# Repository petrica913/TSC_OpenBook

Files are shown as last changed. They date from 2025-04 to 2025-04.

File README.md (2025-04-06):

# 📘 OpenBook - EBook Reader with ESP32-C6

## 📊 Block diagram
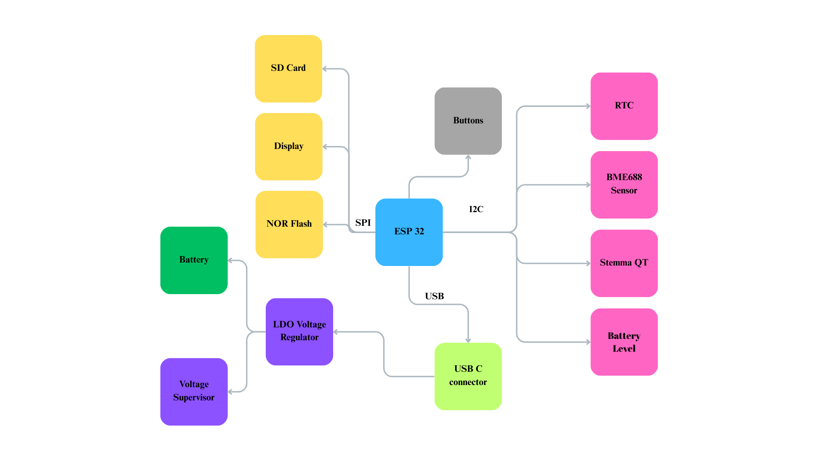
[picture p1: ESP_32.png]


## 🧠 Detailed Hardware Description

### Microcontroller
- **ESP32-C6-WROOM-1-N8** – Main MCU with WiFi 6 and BLE 5.0 support.
- Manages all components and communication interfaces.

### Power Supply
- **USB-C Connector (J2)** – for powering and charging the device.
- **MCP73831** – LiPo battery charging IC.
- **P-Channel MOSFETs (Q1, Q2)** – for automatic switching between USB and battery power.
- **Varistor and 5.1kΩ resistors** – for overvoltage protection and USB-C detection.

### Display
- **eInk display** controlled via **SPI** interface:
  - Lines: CLK, MOSI, CS, DC (Data/Command), RST (Reset), BUSY (status).
  - Extremely power-efficient – consumes power only during screen refresh.

### User Interface
- Physical buttons for menu control:
  - Left/Right navigation and Select.
  - Connected to GPIOs configured as input, some with pull-up/down resistors.

### Sensors (optional)
- **BME680** – temperature, humidity, pressure, and VOC sensor.
  - Communicates via I2C.
  - Connected to GPIOs with 10kΩ pull-up resistors.

### Other Components
- Resistors, filtering and decoupling capacitors.
- Status LEDs (optional).

## 🔋 Estimated Power Consumption

| Component | Estimated Current |
|---|---|
| ESP32-C6 (CPU active, without Wi-Fi) | ~80–120 mA |
| E-Paper (page refresh) | ~10–15 mA *(only during refresh)* |
| MicroSD (active access) | ~30–60 mA |
| RTC DS3231 | ~0.2 mA |
| BME688 Sensor (1Hz) | ~3.7 µA |
| Fuel Gauge MAX17048 (active) | ~23 µA |
| LDO Regulator (quiescent current) | ~1 µA |
| **Total estimated (without refresh)** | **~110–130 mA** |
| **Total during EPD refresh** | **~140–170 mA** |

## 🔌 Pin Allocation of ESP32-C6

| Pin Number | GPIO | Function | Componenta | Reason for Use |
|---|---|---|---|---|
| 3 | EN | Reset | Reset Button | Hardware-defined enable pin |
| 8 | GPIO0 | SQW/INT | RTC DS3231SN Interrupt | Used to wakeup from sleep using an interrupt from RTC  |
| 9 | GPIO1 | 32KHz input | RTC DS3231SN 32KHz output | Low power timing source for RTC operations |
| 27 | GPIO2 | MISO | SD Card, E-Paper, NOR Flash | SPI MISO - receives data from connected peripherals |
| 28 | GPIO3 | EPD_BUSY | E-Paper Display busy signal | Indicates the status of the E-Paper display |
| 30 | GPIO4 | SD_CS | SD Card chip select | Selects the SD card on the SPI bus |
| 31 | GPIO5 | EPD_DC | E-Paper Display data/command | Distinguishes data/command |
| 32 | GPIO6 | SCK | SD Card, E-Paper, NOR Flash | SPI clock line |
| 33 | GPIO7 | MOSI | SD Card, E-Paper, NOR Flash | SPI data line |
| 10 | GPIO8 | Pull-up | Reserved - Unused | Left free |
| 13 | GPIO9 | Boot | Boot Button | Enter flashing mode |
| 14 | GPIO10 | EPD_CS | E-Paper Display chip select | Selects E-Paper |
| 15 | GPIO11 | FLASH_CS | NOR Flash chip select | Selects external flash |
| 16 | GPIO12 | USB_D- | USB Data negative | USB data line |
| 17 | GPIO13 | USB_D+ | USB Data positive | USB data line |
| 23 | GPIO15 | Navigation | Change Button | Input detection |
| 25 | GPIO16 | TX | Test Pad | TX |
| 24 | GPIO17 | RX | Test Pad | RX |
| 16 | GPIO18 | RTC_RST | RTC reset | Resets RTC module |
| 17 | GPIO19 | I2C_PW | BME688 power control | Powers I2C modules |
| 18 | GPIO20 | EPD_3V3 | DMG2305UX-7 | Controls power supply to E-Paper display |
| 19 | GPIO21 | SDA | I2C data (RTC, BME688, Battery Gauge) | I2C data line |
| 20 | GPIO22 | SCL | I2C clock (RTC, BME688, Battery Gauge)| I2C clock line |
| 21 | GPIO23 | EPD_RST | E-Paper Display reset | Resets the display |

## 📋 Bill of Materials (BOM)
[The bill of materials can be found here](Manufacturing/BOM_OpenBook.csv)

## 🎬 Video of the OpenBook
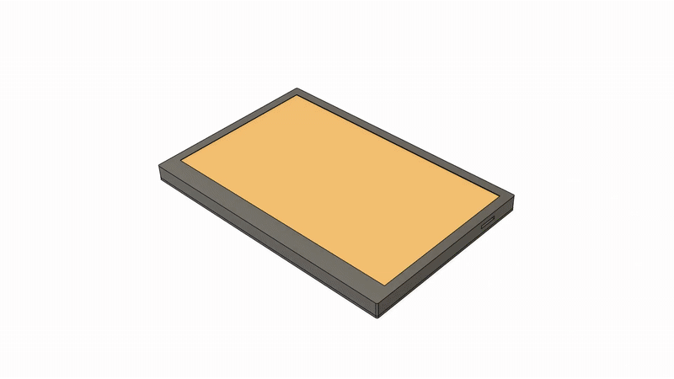
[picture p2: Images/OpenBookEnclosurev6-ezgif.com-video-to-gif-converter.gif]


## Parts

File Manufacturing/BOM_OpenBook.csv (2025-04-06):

Qty | Value | Device | Package | Parts | Description | ARROW_PART_NUMBER | ARROW_PRICE-STOCK | AVAILABILITY | CENTROID_NOT_SPECIFIED | CHECK_PRICES | COPYRIGHT | DATASHEET | DESCRIPTION | DIGIKEY_DESCRIPTION | DIGIKEY_PART_NUMBER | HEIGHT | LEAD_FREE | MANUFACTURER_NAME | MANUFACTURER_PART_NUMBER | MF | MFR_NAME | MOUSER_PART_NUMBER | MOUSER_PRICE-STOCK | MOUSER_TESTING_PART_NUMBER | MOUSER_TESTING_PRICE-STOCK | MP | MPN | PACKAGE | POPULARITY | PREFIX | PRICE | PRODUCT | PROD_ID | PURCHASE-URL | ROHS | SNAPEDA_LINK | SPICEMODEL | SPICEPREFIX | TANT | TEMPERATURE_RANGE_HIGH | TEMPERATURE_RANGE_LOW | TP_SIGNAL_NAME | VALUE
1 |  | ADAFRUIT_LEDCHIP-LED0603 | ADAFRUIT_CHIP-LED0603 | CHG_LED | LED |  |  |  |  | https://www.snapeda.com/parts/KP-1608SURCK/Kingbright/view-part/?ref=search&t=LED%200603
1 |  | SJ | SJ | SJ1 | SMD solder JUMPER |  |  |  |  | https://grabcad.com/library/solder-jumpers-1 |  |  |  |  |  |  |  |  |  |  |  |  |  |  |  |  |  |  | 3
1 | 0.1uF/50V | EAGLE-LTSPICE_CC0402 | EAGLE-LTSPICE_C0402 | EPD_C5 | CAPACITOR, European symbol |  |  |  |  | https://eu.mouser.com/ProductDetail/KEMET/C0805C104K8RACAUTO?qs=ds50AKTGxA8vmn6TMGYnqg%3D%3D |  |  |  |  |  |  |  |  |  |  |  |  |  |  |  |  |  |  |  |  |  |  |  |  |  |  | NONE | C
1 | 0.47 | ESP32_WROVER_EAGLE-LTSPICE_RR0402 | ESP32_WROVER_EAGLE-LTSPICE_R0402 | R3 | RESISTOR, European symbol |  |  |  |  | https://componentsearchengine.com/part-view/R0402%201%25%20100%20K%20(RC0402FR-07100KL)/YAGEO |  |  |  |  |  |  |  |  |  |  |  |  |  |  |  |  |  |  |  |  |  |  |  |  |  |  | NONE | R
1 | 100k | ESP32_WROVER_EAGLE-LTSPICE_RR0402 | ESP32_WROVER_EAGLE-LTSPICE_R0402 | R1_PWRUSB | RESISTOR, European symbol |  |  |  |  | https://componentsearchengine.com/part-view/R0402%201%25%20100%20K%20(RC0402FR-07100KL)/YAGEO |  |  |  |  |  |  |  |  |  |  |  |  |  |  |  |  |  |  |  |  |  |  |  |  |  |  | NONE | R
8 | 100nF | EAGLE-LTSPICE_CC0402 | EAGLE-LTSPICE_C0402 | C1, C2, C4_USB, C6, C8, C9, C10, C_DELAY | CAPACITOR, European symbol |  |  |  |  | https://eu.mouser.com/ProductDetail/KEMET/C0805C104K8RACAUTO?qs=ds50AKTGxA8vmn6TMGYnqg%3D%3D |  |  |  |  |  |  |  |  |  |  |  |  |  |  |  |  |  |  |  |  |  |  |  |  |  |  | NONE | C
1 | 100uF | RCL_CPOL-EUCT3528 | RCL_CT3528 | C3 | POLARIZED CAPACITOR, European symbol |  |  |  |  | https://www.snapeda.com/parts/20TDC100MYF/Panasonic/view-part/ |  |  |  |  |  |  |  |  |  |  |  |  |  |  |  |  |  |  | 0 |  |  |  |  |  |  |  |  | C
16 | 10K | ESP32_WROVER_EAGLE-LTSPICE_RR0402 | ESP32_WROVER_EAGLE-LTSPICE_R0402 | R1, R1_PINH, R1_PINH1, R2_PINH, R2_PINH1, R4, R5, R6, R7, R8, R9, R10, R_BOOT, R_CHANGE, R_CL1, R_RESET | RESISTOR, European symbol |  |  |  |  | https://componentsearchengine.com/part-view/R0402%201%25%20100%20K%20(RC0402FR-07100KL)/YAGEO |  |  |  |  |  |  |  |  |  |  |  |  |  |  |  |  |  |  |  |  |  |  |  |  |  |  | NONE | R
1 | 10uF | EAGLE-LTSPICE_CC0402 | EAGLE-LTSPICE_C0402 | C7 | CAPACITOR, European symbol |  |  |  |  | https://eu.mouser.com/ProductDetail/KEMET/C0805C104K8RACAUTO?qs=ds50AKTGxA8vmn6TMGYnqg%3D%3D |  |  |  |  |  |  |  |  |  |  |  |  |  |  |  |  |  |  |  |  |  |  |  |  |  |  | NONE | C
1 | 112A-TAAR-R03_ATTEND | 112A-TAAR-R03_ATTEND | 112ATAARR03ATTEND | J4 | Micro SD Card Socket, Push-Push Type, Top Mount, SMT, H=1.83mm, 10u |  |  |  |  | https://store.comet.srl.ro/Catalogue/Product/43497/ |  |  | Micro SD Card Socket | Push-Push Type | Top Mount | SMT | H=1.83mm | 10u |  |  | 1.9mm |  | ATTEND | 112A-TAAR-R03 ATTEND
1 | 15 | ESP32_WROVER_EAGLE-LTSPICE_RR0402 | ESP32_WROVER_EAGLE-LTSPICE_R0402 | R_CAPACITOR | RESISTOR, European symbol |  |  |  |  | https://componentsearchengine.com/part-view/R0402%201%25%20100%20K%20(RC0402FR-07100KL)/YAGEO |  |  |  |  |  |  |  |  |  |  |  |  |  |  |  |  |  |  |  |  |  |  |  |  |  |  | NONE | R
1 | 1uF | EAGLE-LTSPICE_CC0402 | EAGLE-LTSPICE_C0402 | C5 | CAPACITOR, European symbol |  |  |  |  | https://eu.mouser.com/ProductDetail/KEMET/C0805C104K8RACAUTO?qs=ds50AKTGxA8vmn6TMGYnqg%3D%3D |  |  |  |  |  |  |  |  |  |  |  |  |  |  |  |  |  |  |  |  |  |  |  |  |  |  | NONE | C
9 | 1uF/50V | EAGLE-LTSPICE_CC0402 | EAGLE-LTSPICE_C0402 | EPD_C1, EPD_C2, EPD_C6, EPD_C7, EPD_C8, EPD_C9, EPD_C10, EPD_C11, EPD_C12 | CAPACITOR, European symbol |  |  |  |  | https://eu.mouser.com/ProductDetail/KEMET/C0805C104K8RACAUTO?qs=ds50AKTGxA8vmn6TMGYnqg%3D%3D |  |  |  |  |  |  |  |  |  |  |  |  |  |  |  |  |  |  |  |  |  |  |  |  |  |  | NONE | C
1 | 2.2 | ESP32_WROVER_EAGLE-LTSPICE_RR0402 | ESP32_WROVER_EAGLE-LTSPICE_R0402 | R2 | RESISTOR, European symbol |  |  |  |  | https://componentsearchengine.com/part-view/R0402%201%25%20100%20K%20(RC0402FR-07100KL)/YAGEO |  |  |  |  |  |  |  |  |  |  |  |  |  |  |  |  |  |  |  |  |  |  |  |  |  |  | NONE | R
1 | 200 | ESP32_WROVER_EAGLE-LTSPICE_RR0402 | ESP32_WROVER_EAGLE-LTSPICE_R0402 | R1_BAT | RESISTOR, European symbol |  |  |  |  | https://componentsearchengine.com/part-view/R0402%201%25%20100%20K%20(RC0402FR-07100KL)/YAGEO |  |  |  |  |  |  |  |  |  |  |  |  |  |  |  |  |  |  |  |  |  |  |  |  |  |  | NONE | R
1 | 20V/4.2A/52mO/1.4W | ESP32_WROVER_SPARKFUN-DISCRETESEMI_MOSFET_PCH-DMG2305UX-7 | ESP32_WROVER_SPARKFUN-DISCRETESEMI_SOT23-3 | Q1 | P-channel MOSFETs |  |  |  |  | https://componentsearchengine.com/part-view/DMG2305UX-7/Diodes%20Incorporated |  |  |  |  |  |  |  |  |  |  |  |  |  |  |  |  |  |  |  |  |  |  | TRAN-14388 |  |  |  |  |  |  |  |  |  | 20V/4.2A/52mO/1.4W
1 | 20V/4.2A/52mO/1.4W | ESP32_WROVER_SPARKFUN-DISCRETESEMI_MOSFET_PCH-DMG2305UX-7 | ESP32_WROVER_SPARKFUN-DISCRETESEMI_SOT23-3 | Q2 | P-channel MOSFETs |  |  |  |  | https://componentsearchengine.com/part-view/DMG2305UX-7/Diodes%20Incorporated |  |  |  |  |  |  |  |  |  |  |  |  |  |  |  |  |  |  |  |  |  | DMG2305UX-7 | TRAN-14388 |  |  |  |  |  |  |  |  |  | 20V/4.2A/52mO/1.4W
1 | 2K | ESP32_WROVER_EAGLE-LTSPICE_RR0402 | ESP32_WROVER_EAGLE-LTSPICE_R0402 | R2_BAT | RESISTOR, European symbol |  |  |  |  | https://componentsearchengine.com/part-view/R0402%201%25%20100%20K%20(RC0402FR-07100KL)/YAGEO |  |  |  |  |  |  |  |  |  |  |  |  |  |  |  |  |  |  |  |  |  |  |  |  |  |  | NONE | R
5 | 4.7uF | EAGLE-LTSPICE_CC0402 | EAGLE-LTSPICE_C0402 | C1_BAT, C1_BAT1, C1_BAT2, C2_BAT, C5_USB | CAPACITOR, European symbol |  |  |  |  | https://eu.mouser.com/ProductDetail/KEMET/C0805C104K8RACAUTO?qs=ds50AKTGxA8vmn6TMGYnqg%3D%3D |  |  |  |  |  |  |  |  |  |  |  |  |  |  |  |  |  |  |  |  |  |  |  |  |  |  | NONE | C
1 | 4.7uF/25V | EAGLE-LTSPICE_CC0402 | EAGLE-LTSPICE_C0402 | C4 | CAPACITOR, European symbol |  |  |  |  | https://eu.mouser.com/ProductDetail/KEMET/C0805C104K8RACAUTO?qs=ds50AKTGxA8vmn6TMGYnqg%3D%3D |  |  |  |  |  |  |  |  |  |  |  |  |  |  |  |  |  |  |  |  |  |  |  |  |  |  | NONE | C
2 | 5k1 | ESP32_WROVER_EAGLE-LTSPICE_RR0402 | ESP32_WROVER_EAGLE-LTSPICE_R0402 | R1-USB, R2-USB1 | RESISTOR, European symbol |  |  |  |  | https://componentsearchengine.com/part-view/R0402%201%25%20100%20K%20(RC0402FR-07100KL)/YAGEO |  |  |  |  |  |  |  |  |  |  |  |  |  |  |  |  |  |  |  |  |  |  |  |  |  |  | NONE | R
1 | 744043680IND_4828-WE-TPC_WRE | 744043680IND_4828-WE-TPC_WRE | IND_4828-WE-TPC_WRE | L1 |  |  |  |  |  | https://eu.mouser.com/ProductDetail/Wurth-Elektronik/744043680?qs=PGXP4M47uW6VkZq%252BkzjrHA%3D%3D | Copyright (C) 2024 Ultra Librarian. All rights reserved. |  |  |  |  |  |  |  | 68uH |  | Wurth Electronics
1 | BD5229G-TR | BD5229G-TR | SOT95P280X125-5N | IC1 | Voltage Detector with Adjustable Delay Time: CMOS processes are utilized to develop high precision, low current consumption CMOS reset ICs that allow arbitrary setting of the delay time. The extensive lineup includes both Nch Open Drain and CMOS output types in a wide range of detection voltages (from 2.3V to 6.0V, in 0.1V steps), enabling selection of the ideal solution based on customer requirements. In addition, the entire series is of course both lead-free and RoHS-compliant. |  |  |  |  | https://componentsearchengine.com/part-view/BD5229G-TR/ROHM%20Semiconductor |  |  | Voltage Detector with Adjustable Delay Time: CMOS processes are utilized to develop high precision | low current consumption CMOS reset ICs that allow arbitrary setting of the delay time. The extensive lineup includes both Nch Open Drain and CMOS output types in a wide range of detection voltages (from 2.3V to 6.0V | in 0.1V steps) | enabling selection of the ideal solution based on customer requirements. In addition | the entire series is of course both lead-free and RoHS-compliant. |  |  | 1.25mm |  | ROHM Semiconductor | BD5229G-TR |  |  | 755-BD5229G-TR | https://www.mouser.co.uk/ProductDetail/ROHM-Semiconductor/BD5229G-TR?qs=4kLU8WoGk0vvnhrrYwdszw%3D%3D
3 | BUTTON_CUSYOMV1 | BUTTON_CUSYOMV1 | MYBUTTON | BOOT_BUTTON, CHANGE_BUTTON, RESET_BUTTON |  |  |  |  |  | https://industry.panasonic.com/global/en/products/control/switch/light-touch/number/evqpuj02k
1 | CPH3225A | CPH3225A | CAPCP3225X100N | C10_SUPERCAP | Cap 0.011F 3.3V 1210 Flat Check availability |  |  | Not in stock |  | https://www.snapeda.com/parts/CPH3225A/Seiko+Instruments/view-part/?ref=eda |  |  | 11 mF (EDLC) Supercapacitor 3.3 V 1210 (3225 Metric) - - |  |  |  |  |  |  | Seiko Instruments |  |  |  |  |  | CPH3225A |  | 1210 Seiko |  |  | None |  |  | https://www.snapeda.com/api/url_track_click_mouser/?unipart_id=562593&manufacturer=Seiko Instruments&part_name=CPH3225A&search_term=None |  | https://www.snapeda.com/parts/CPH3225A/Seiko+Instruments/view-part/?ref=snap
1 | DS3231SN# | DS3231SN# | SOIC127P1032X265-16N | U3 | Real Time Clock Serial 16-Pin SOIC W T/R Check availability |  |  | In Stock |  | https://www.snapeda.com/parts/DS3231SN%23/Analog+Devices/view-part/?ref=eda |  |  | Extremely Accurate I²C-Integrated RTC/TCXO/Crystal |  |  |  |  |  |  | Analog Devices |  |  |  |  |  | DS3231SN# |  | SOIC-16 Maxim |  |  | None |  |  | https://www.snapeda.com/api/url_track_click_mouser/?unipart_id=99048&manufacturer=Analog Devices&part_name=DS3231SN#&search_term=None |  | https://www.snapeda.com/parts/DS3231SN%23/Analog+Devices/view-part/?ref=snap
1 | ESP32-C6-WROOM-1-N8 | ESP32-C6-WROOM-1-N8 | XCVR_ESP32-C6-WROOM-1-N8 | U2 | Check availability |  |  | In Stock |  | https://www.snapeda.com/parts/ESP32-C6-WROOM-1-N8/Espressif+Systems/view-part/?ref=eda |  |  | Multiprotocol Modules ESP32-C6 module | Wi-Fi 6 in 2.4 GHz band | Bluetooth 5 | Zigbee 3.0 and Thread. ESP34-WROOM Compatible - ENGINEERING SAMPLE |  |  |  |  |  |  | Espressif Systems |  |  |  |  |  | ESP32-C6-WROOM-1-N8 |  | None |  |  | None |  |  |  |  | https://www.snapeda.com/parts/ESP32-C6-WROOM-1-N8/Espressif+Systems/view-part/?ref=snap
1 | ESP32C6_VARISTORCN1812 | ESP32C6_VARISTORCN1812 | ESP32C6_VARISTOR_CT/CN1812 | PFMF.050.1 | VARISTOR |  |  |  |  | https://www.mouser.co.uk/ProductDetail/EPCOS-TDK/B72520T0350K062?qs=dEfas%2FXlABIszF52uu7vrg%3D%3D |  |  |  |  |  |  |  |  |  |  |  |  |  |  |  |  |  |  | 0
2 | ESP32_WROVER_AVX---SD0805S020S1R0_AVX_SD0805S020S1R0_0_0AVX_SD0805S020S1R0_0_0 | ESP32_WROVER_AVX---SD0805S020S1R0_AVX_SD0805S020S1R0_0_0AVX_SD0805S020S1R0_0_0 | ESP32_WROVER_AVX---SD0805S020S1R0_AVX_SD0805S020S1R0_0 | D2, D7 | Schottky Barrier Rectifier Diode |  |  |  | No | https://eu.mouser.com/ProductDetail/KYOCERA-AVX/SD0805S020S1R0?qs=jCA%252BPfw4LHbpkAoSnwrdjw%3D%3D |  | http://datasheets.avx.com/schottky.pdf |  | DIODE SCHOTTKY 20V 1A 0805 | 478-7800-1-ND |  | yes |  |  | AVX |  | 581-SD0805S020S1R0 |  |  |  |  |  | 0805 (2012 metric) |  | D |  |  |  |  | yes |  |  |  |  | +125°C | -55°C
1 | ESP32_WROVER_BME680_BME680 | ESP32_WROVER_BME680_BME680 | ESP32_WROVER_BME680_PSON80P300X300X100-8N | SENSOR2 | Integrated Environmental Unit |  |  | Unavailable |  | https://www.snapeda.com/parts/BME680/Bosch/view-part/?welcome=home |  |  | Integrated Environmental Unit |  |  |  |  |  |  | Bosch Sensortec |  |  |  |  |  | BME680 |  | LGA-8 Bosch Tools |  |  | None
1 | ESP32_WROVER_SPARKFUN-IC-POWER_MCP73831 | ESP32_WROVER_SPARKFUN-IC-POWER_MCP73831 | ESP32_WROVER_SPARKFUN-IC-POWER_SOT23-5 | MCP73831 | MCP73831T Li-Ion, Li-Pol Controller |  |  |  |  | https://www.digikey.ro/en/products/detail/microchip-technology/MCP73831T-2ACI-OT/964301 |  |  |  |  |  |  |  |  |  |  |  |  |  |  |  |  |  |  |  |  |  |  | IC-09995
1 | FH34SRJ-24S-0.5SH_99_ | FH34SRJ-24S-0.5SH_99_ | FH34SRJ24S05SH99 | J1 | (0.50mm) Surface Mount, Right Angle |  |  |  |  | https://componentsearchengine.com/part-view/XC6220A331MR-G/Torex |  |  | 24 Position FFC | FPC Connector Contacts | (0.50mm) Surface Mount | Right Angle |  |  | 1.1mm |  | Hirose | FH34SRJ-24S-0.5SH(99) |  |  | 798-FH34SRJ24S05SH99 | https://www.mouser.co.uk/ProductDetail/Hirose-Connector/FH34SRJ-24S-0.5SH99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
1 | MAX17048G+T10 | MAX17048G+T10 | SON50P200X200X80-9N | U4 | Check availability |  |  | In Stock |  | https://www.snapeda.com/parts/MAX17048G+T10/Analog+Devices/view-part/?ref=eda |  |  | 3µA 1-Cell/2-Cell Fuel Gauge with ModelGauge |  |  |  |  |  |  | Analog Devices |  |  |  |  |  | MAX17048G+T10 |  | TDFN-8 Maxim |  |  | None |  |  | https://www.snapeda.com/api/url_track_click_mouser/?unipart_id=329239&manufacturer=Analog Devices&part_name=MAX17048G+T10&search_term=None |  | https://www.snapeda.com/parts/MAX17048G+T10/Analog+Devices/view-part/?ref=snap
3 | MBR0530 | MBR0530 | SOD3716X135N | D3, D4, D5 | ON SEMICONDUCTOR - MBR0530 - DIODE, SCHOTTKY, 0.5A, 30V, SOD-123 |  |  | In Stock |  | https://www.snapeda.com/parts/MBR0530/Onsemi/view-part/?ref=eda |  |  | Diode Schottky 30 V 500mA Surface Mount SOD-123 |  |  |  |  |  |  | ON Semiconductor |  |  |  |  |  | MBR0530 |  | SOD-123-2 ON Semiconductor |  |  | None |  |  | https://www.snapeda.com/api/url_track_click_mouser/?unipart_id=179458&manufacturer=ON Semiconductor&part_name=MBR0530&search_term=None |  | https://www.snapeda.com/parts/MBR0530/Onsemi/view-part/?ref=snap
6 | PGB1010603MR | PGB1010603MR | DIOC1608X36N | D6, D8, D9, D10, D11, D12 | Check availability |  |  | In Stock |  | https://www.snapeda.com/parts/PGB1010603MR/Littelfuse/view-part/?ref=eda |  |  | 150V (Typ) Clamp - Ipp Tvs Diode Surface Mount 0603 (1608 Metric) |  |  |  |  |  |  | Littelfuse Inc. |  |  |  |  |  | PGB1010603MR |  | 0603 Littelfuse Inc. |  |  | None |  |  | https://www.snapeda.com/api/url_track_click_mouser/?unipart_id=5659453&manufacturer=Littelfuse Inc.&part_name=PGB1010603MR&search_term=None |  | https://www.snapeda.com/parts/PGB1010603MR/Littelfuse/view-part/?ref=snap
1 | QWIIC_RIGHT_ANGLE | QWIIC_CONNECTORJS-1MM | JST04_1MM_RA | J3 | SparkFun I2C Standard Qwiic Connector |  |  |  |  | https://www.digikey.ro/en/models/926710 |  |  |  |  |  |  |  |  |  |  |  |  |  |  |  |  |  |  |  |  |  |  | CONN-13694 |  |  |  |  |  |  |  |  |  | QWIIC_RIGHT_ANGLE
1 | SAMACSYS_PARTS_USB4110-GF-A | SAMACSYS_PARTS_USB4110-GF-A | SAMACSYS_PARTS_USB4110GFA | J2 | CONN USB 2.0 TYPE-C R/A SMT |  |  |  |  | https://componentsearchengine.com/part-view/USB4110-GF-A/GCT%20(GLOBAL%20CONNECTOR%20TECHNOLOGY) |  |  | CONN USB 2.0 TYPE-C R/A SMT |  |  | 3.26mm |  | GCT (GLOBAL CONNECTOR TECHNOLOGY) | USB4110-GF-A |  |  | 640-USB4110-GF-A | https://www.mouser.co.uk/ProductDetail/GCT/USB4110-GF-A?qs=KUoIvG%2F9IlYiZvIXQjyJeA%3D%3D
1 | SI1308EDL-T1-GE3 | SI1308EDL-T1-GE3 | SOT65P210X110-3N | Q3 | MOSFET N-Ch 30V 1.5A TrenchFET SC70 Vishay Si1308EDL-T1-GE3 N-channel MOSFET Transistor, 1.5 A, 30 V, 3-Pin SC-70 |  |  | In Stock |  | https://www.snapeda.com/parts/SI1308EDL-T1-GE3/Vishay+Siliconix/view-part/?ref=eda |  |  | Si1308EDL-T1-GE3 N-channel MOSFET Transistor | 1.5 A | 30 V | 3-Pin SC-70 | Siliconix / Vishay SI1308EDL-T1-GE3 |  |  |  |  |  |  | Vishay Siliconix |  |  |  |  |  | SI1308EDL-T1-GE3 |  | SOT-323 Vishay Semiconductor |  |  | None |  |  | https://www.snapeda.com/api/url_track_click_mouser/?unipart_id=274603&manufacturer=Vishay Siliconix&part_name=SI1308EDL-T1-GE3&search_term=None |  | https://www.snapeda.com/parts/SI1308EDL-T1-GE3/Vishay+Siliconix/view-part/?ref=snap
17 | TPTP20R | TPTP20R | TP20R | TP1, TP2, TP3, TP4, TP5, TP6, TP7, TP8, TP9, TP10, TP11, TP12, TP13, TP14, TP15, TP16, TP17 | Test pad |  |  |  |  | https://grabcad.com/library/test-points-printed-circuit-board-1 |  |  |  |  |  |  |  |  |  |  |  |  |  |  |  |  |  |  | 2
1 | USBLC6-2SC6Y | USBLC6-2SC6Y | SOT95P280X145-6N | D1 | Low Cap. ESD Protection Auto SOT-23-6 STMicroelectronics USBLC6-2SC6Y, Dual Uni-Directional TVS Diode Array, 6-Pin SOT-23 |  |  | In Stock |  | https://www.snapeda.com/parts/USBLC6-2SC6Y/STMicroelectronics/view-part/?ref=eda |  |  | 17V Clamp 5A (8/20µs) Ipp Tvs Diode Surface Mount SOT-23-6 |  |  |  |  |  |  | STMicroelectronics |  |  |  |  |  | USBLC6-2SC6Y |  | SOT-23-6 STMicroelectronics |  |  | None |  |  |  |  | https://www.snapeda.com/parts/USBLC6-2SC6Y/STMicroelectronics/view-part/?ref=snap
1 | W25Q512JVEIQ | W25Q512JVEIQ | SON127P600X800X80-9N | U1 | Check availability |  |  | In Stock |  | https://www.snapeda.com/parts/W25Q512JVEIQ/Winbond+Electronics/view-part/?ref=eda |  |  | FLASH - NOR Memory IC 512Mb (64M x 8) SPI - Quad I/O 133 MHz 8-WSON (8x6) |  |  |  |  |  |  | Winbond Electronics |  |  |  |  |  | W25Q512JVEIQ |  | Package |  |  | None |  |  |  |  | https://www.snapeda.com/parts/W25Q512JVEIQ/Winbond+Electronics/view-part/?ref=snap
1 | XC6220A331MR-G | XC6220A331MR-G | SOT95P280X120-5N | IC4 | LDO Voltage Regulators |  |  |  |  | https://componentsearchengine.com/part-view/XC6220A331MR-G/Torex |  |  | LDO Voltage Regulators |  |  | 1.2mm |  | Torex | XC6220A331MR-G |  |  | 865-XC6220A331MR-G | https://www.mouser.co.uk/ProductDetail/Torex-Semiconductor/XC6220A331MR-G?qs=AsjdqWjXhJ8ZSWznL1J0gg%3D%3D

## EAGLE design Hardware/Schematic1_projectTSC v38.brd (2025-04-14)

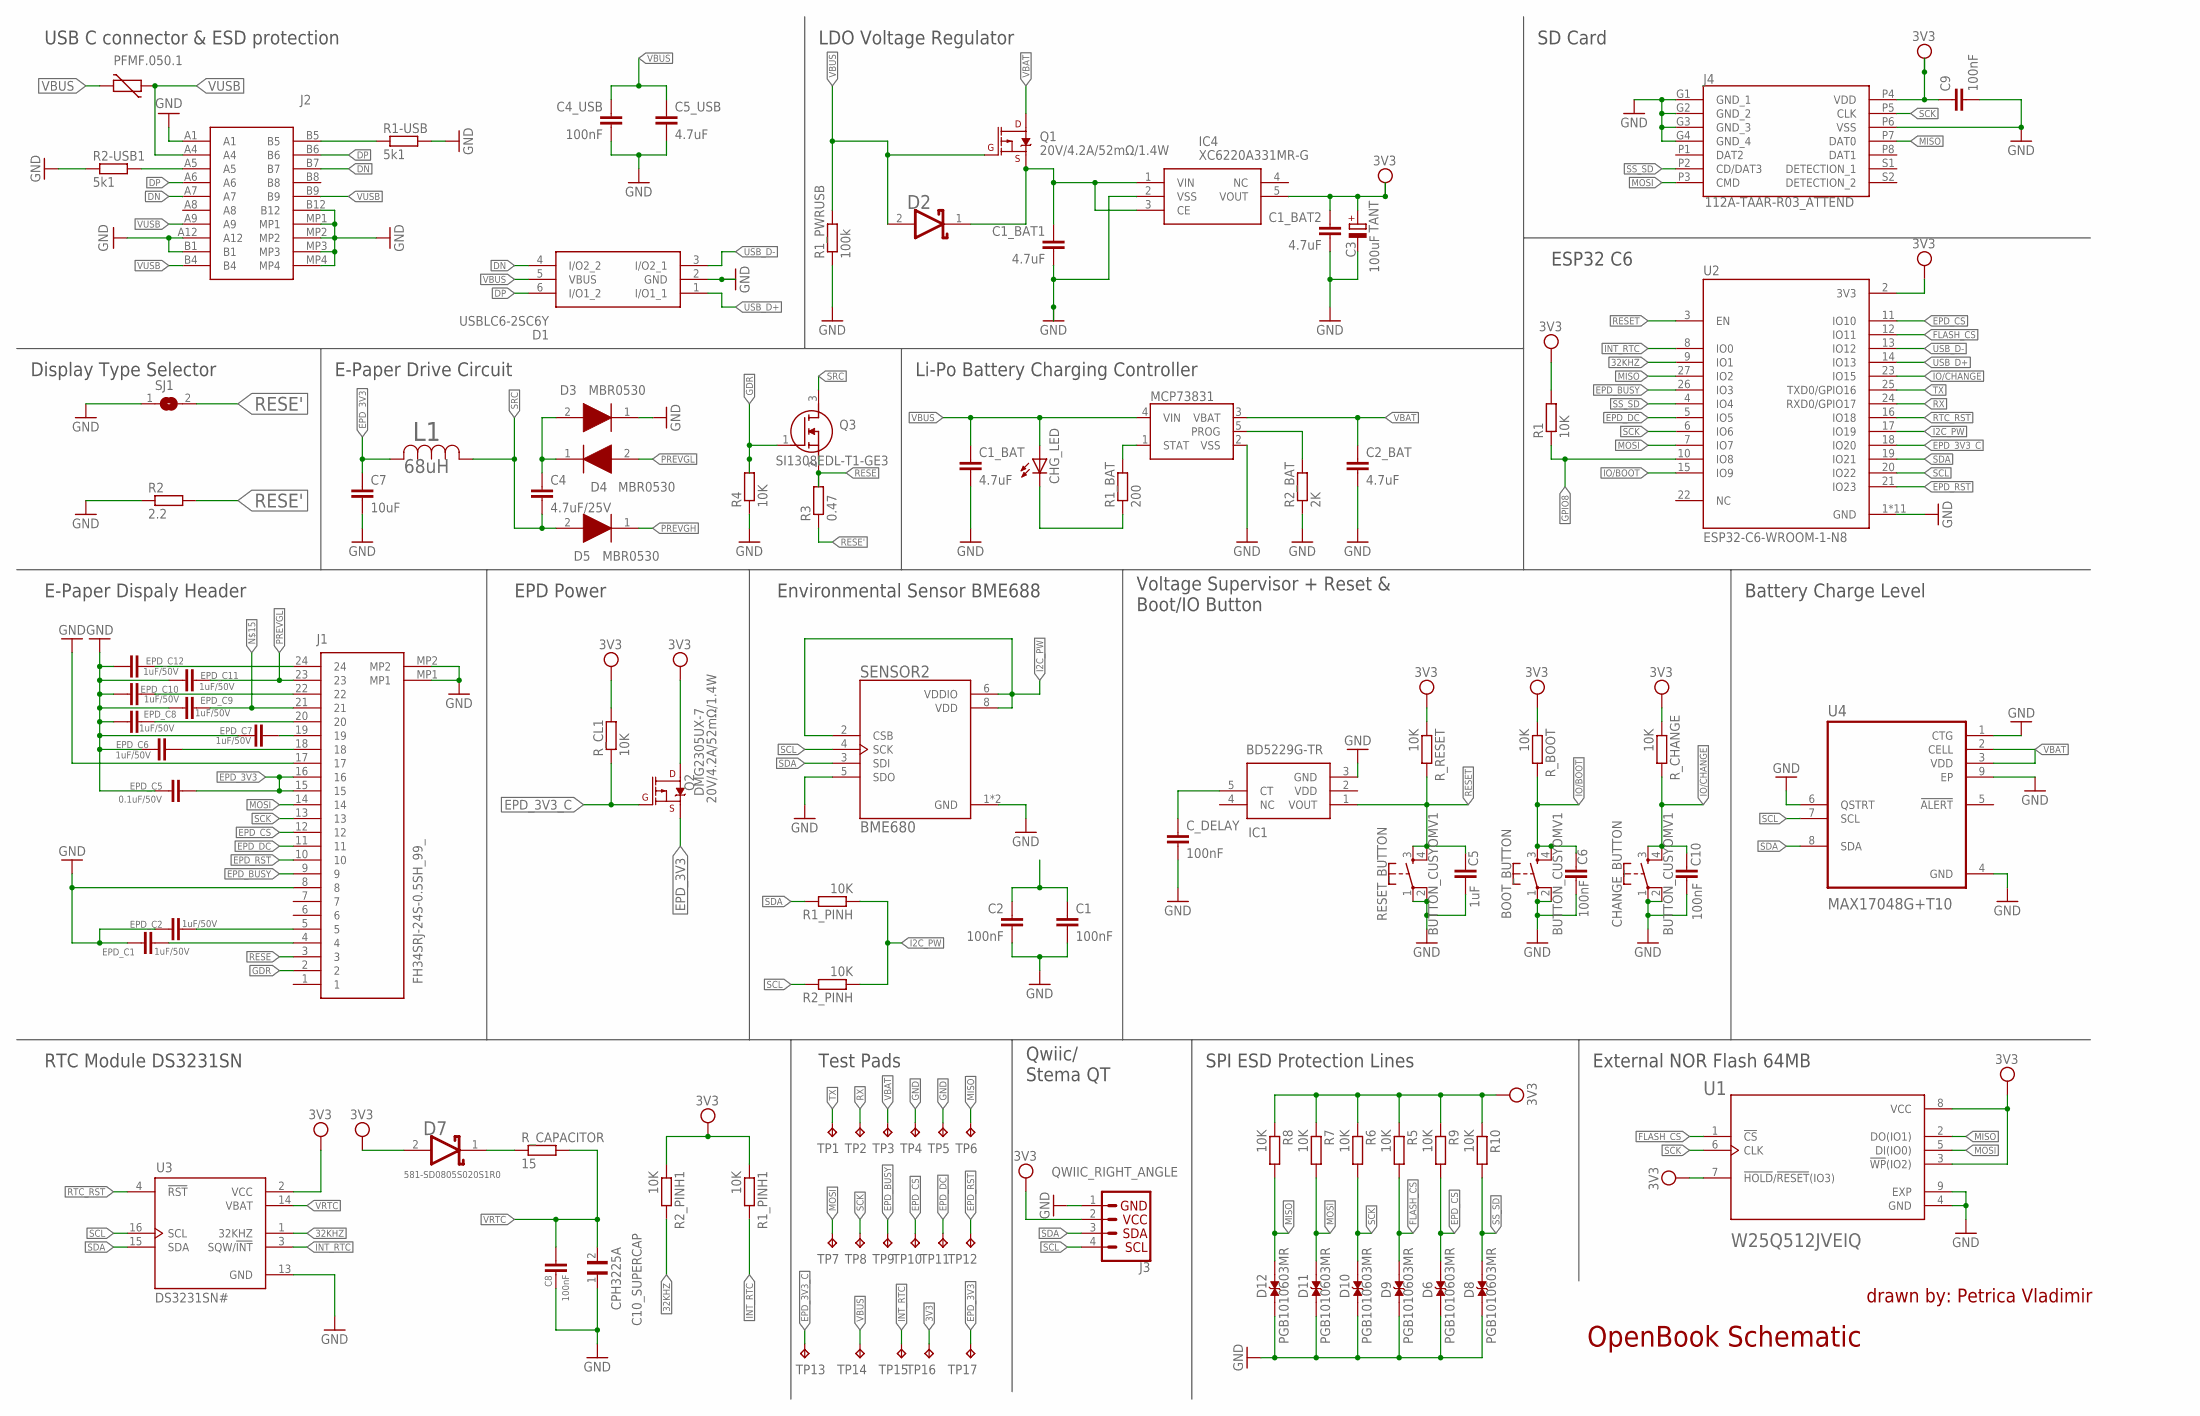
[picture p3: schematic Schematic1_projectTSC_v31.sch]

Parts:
BOOT_BUTTON: BUTTON_CUSYOMV1; MYBUTTON
C1, C2, C4_USB, C6, C8, C9, C10: 100nF; EAGLE-LTSPICE_C0402
C1_BAT, C1_BAT1, C1_BAT2, C2_BAT, C5_USB: 4.7uF; EAGLE-LTSPICE_C0402
C3: 100uF; RCL_CT3528
C4: 4.7uF/25V; EAGLE-LTSPICE_C0402
C5: 1uF; EAGLE-LTSPICE_C0402
C7: 10uF; EAGLE-LTSPICE_C0402
C10_SUPERCAP: CPH3225A; CAPCP3225X100N
CHANGE_BUTTON: BUTTON_CUSYOMV1; MYBUTTON
CHG_LED: ADAFRUIT_LEDCHIP-LED0603; ADAFRUIT_CHIP-LED0603
C_DELAY: 100nF; EAGLE-LTSPICE_C0402
D1: USBLC6-2SC6Y; SOT95P280X145-6N
D2, D7: ESP32_WROVER_AVX---SD0805S020S1R0_AVX_SD0805S020S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; ESP32_WROVER_AVX---SD0805S020S1R0_AVX_SD0805S020S1R0_0
D3, D4, D5: MBR0530; SOD3716X135N
D6, D8, D9, D10, D11, D12: PGB1010603MR; DIOC1608X36N
EPD_C1, EPD_C2, EPD_C6, EPD_C7, EPD_C8, EPD_C9, EPD_C10, EPD_C11, EPD_C12: 1uF/50V; EAGLE-LTSPICE_C0402
EPD_C5: 0.1uF/50V; EAGLE-LTSPICE_C0402
IC1: BD5229G-TR; SOT95P280X125-5N
IC4: XC6220A331MR-G; SOT95P280X120-5N
J1: FH34SRJ-24S-0.5SH_99_; FH34SRJ24S05SH99
J2: SAMACSYS_PARTS_USB4110-GF-A; SAMACSYS_PARTS_USB4110GFA
J3: QWIIC_RIGHT_ANGLE; JST04_1MM_RA
J4: 112A-TAAR-R03_ATTEND; 112ATAARR03ATTEND
L1: 744043680IND_4828-WE-TPC_WRE; IND_4828-WE-TPC_WRE; MANUFACTURER_PART_NUMBER 68uH
MCP73831: ESP32_WROVER_SPARKFUN-IC-POWER_MCP73831; ESP32_WROVER_SPARKFUN-IC-POWER_SOT23-5
PFMF.050.1: ESP32C6_VARISTORCN1812; ESP32C6_VARISTOR_CT/CN1812
Q1, Q2: 20V/4.2A/52mΩ/1.4W; ESP32_WROVER_SPARKFUN-DISCRETESEMI_SOT23-3
Q3: SI1308EDL-T1-GE3; SOT65P210X110-3N
R1, R1_PINH, R1_PINH1, R2_PINH, R2_PINH1, R4, R5, R6, R7, R8, R9, R10: 10K; ESP32_WROVER_EAGLE-LTSPICE_R0402
R1-USB, R2-USB1: 5k1; ESP32_WROVER_EAGLE-LTSPICE_R0402
R1_BAT: 200; ESP32_WROVER_EAGLE-LTSPICE_R0402
R1_PWRUSB: 100k; ESP32_WROVER_EAGLE-LTSPICE_R0402
R2: 2.2; ESP32_WROVER_EAGLE-LTSPICE_R0402
R2_BAT: 2K; ESP32_WROVER_EAGLE-LTSPICE_R0402
R3: 0.47; ESP32_WROVER_EAGLE-LTSPICE_R0402
RESET_BUTTON: BUTTON_CUSYOMV1; MYBUTTON
R_BOOT: 10K; ESP32_WROVER_EAGLE-LTSPICE_R0402
R_CAPACITOR: 15; ESP32_WROVER_EAGLE-LTSPICE_R0402
R_CHANGE: 10K; ESP32_WROVER_EAGLE-LTSPICE_R0402
R_CL1: 10K; ESP32_WROVER_EAGLE-LTSPICE_R0402
R_RESET: 10K; ESP32_WROVER_EAGLE-LTSPICE_R0402
SENSOR2: ESP32_WROVER_BME680_BME680; ESP32_WROVER_BME680_PSON80P300X300X100-8N
SJ1: SJ
TP1, TP2, TP3, TP4, TP5, TP6, TP7, TP8, TP9, TP10, TP11, TP12, TP13, TP14, TP15, TP16, TP17: TPTP20R; TP20R
U1: W25Q512JVEIQ; SON127P600X800X80-9N
U2: ESP32-C6-WROOM-1-N8; XCVR_ESP32-C6-WROOM-1-N8
U3: DS3231SN#; SOIC127P1032X265-16N
U4: MAX17048G+T10; SON50P200X200X80-9N

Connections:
3V3: C1_BAT2.1, C3.+, C9.1, D7.2 (ANODE), IC4.5 (VOUT), J3.2, J4.P4 (VDD), Q2.3 (D), R1.2, R1_PINH1.1, R2_PINH1.1, R5.1, R6.1, R7.1, R8.1, R9.1, R10.1, R_BOOT.1, R_CHANGE.1, R_CL1.2, R_RESET.1, TP16.TP, U1.3 (!WP!(IO2)), U1.7 (!HOLD!/!RESET!(IO3)), U1.8 (VCC), U2.2 (3V3), U3.2 (VCC)
32KHZ: R2_PINH1.2, U2.9 (IO1), U3.1 (32KHZ)
DN: D1.4 (I/O2_2), J2.A7, J2.B7
DP: D1.6 (I/O1_2), J2.A6, J2.B6
EPD_3V3: C7.1, EPD_C5.2, J1.15, J1.16, L1.2, Q2.2 (S), TP17.TP
EPD_3V3_C: Q2.1 (G), R_CL1.1, TP13.TP, U2.18 (IO20)
EPD_BUSY: J1.9, TP9.TP, U2.26 (IO3)
EPD_CS: D6.2, J1.12, R9.2, TP10.TP, U2.11 (IO10)
EPD_DC: J1.11, TP11.TP, U2.5 (IO5)
EPD_RST: J1.10, TP12.TP, U2.21 (IO23)
FLASH_CS: D9.2, R5.2, U1.1 (!CS), U2.12 (IO11)
GDR: J1.2, Q3.1 (G), R4.2
GND: BOOT_BUTTON.1, BOOT_BUTTON.2, C1.2, C1_BAT.2, C1_BAT1.2, C1_BAT2.2, C2.2, C2_BAT.2, C3.-, C4_USB.2, C5.2, C5_USB.2, C6.2, C7.2, C8.1, C9.2, C10.2, C10_SUPERCAP.1, CHANGE_BUTTON.1, CHANGE_BUTTON.2, C_DELAY.2, D1.2 (GND), D3.1 (K), D6.1, D8.1, D9.1, D10.1, D11.1, D12.1, EPD_C1.1, EPD_C2.1, EPD_C5.1, EPD_C6.1, EPD_C7.1, EPD_C8.1, EPD_C9.1, EPD_C10.1, EPD_C11.1, EPD_C12.1, IC1.3 (GND), IC4.2 (VSS), J1.8, J1.17, J1.MP1, J1.MP2, J2.A1, J2.A12, J2.B1, J2.B12, J2.MP1, J2.MP2, J2.MP3, J2.MP4, J3.1, J4.G1 (GND_1), J4.G2 (GND_2), J4.G3 (GND_3), J4.G4 (GND_4), J4.P6 (VSS), MCP73831.2 (VSS), R1-USB.2, R1_PWRUSB.1, R2.1, R2-USB1.1, R2_BAT.1, R4.1, RESET_BUTTON.1, RESET_BUTTON.2, SENSOR2.1 (GND), SENSOR2.5 (SDO), SENSOR2.7 (GND), SJ1.1, TP4.TP, TP5.TP, U1.4 (GND), U1.9 (EXP), U2.1 (GND), U2.28 (GND), U2.29_1 (GND), U2.29_2 (GND), U2.29_3 (GND), U2.29_4 (GND), U2.29_5 (GND), U2.29_6 (GND), U2.29_7 (GND), U2.29_8 (GND), U2.29_9 (GND), U3.13 (GND), U4.1 (CTG), U4.4 (GND), U4.6 (QSTRT), U4.9 (EP)
GPIO8: R1.1, U2.10 (IO8)
I2C_PW: R1_PINH.1, R2_PINH.1, SENSOR2.2 (CSB), SENSOR2.6 (VDDIO), SENSOR2.8 (VDD), U2.17 (IO19)
INT_RTC: R1_PINH1.2, TP15.TP, U2.8 (IO0), U3.3 (SQW/!INT)
IO/BOOT: BOOT_BUTTON.3, BOOT_BUTTON.4, C6.1, R_BOOT.2, U2.15 (IO9)
IO/CHANGE: C10.1, CHANGE_BUTTON.3, CHANGE_BUTTON.4, R_CHANGE.2, U2.23 (IO15)
MISO: D12.2, J4.P7 (DAT0), R8.2, TP6.TP, U1.2 (DO(IO1)), U2.27 (IO2)
MOSI: D11.2, J1.14, J4.P3 (CMD), R7.2, TP7.TP, U1.5 (DI(IO0)), U2.7 (IO7)
unnamed: J2.A5, R2-USB1.2
unnamed: J2.B5, R1-USB.1
unnamed: MCP73831.1 (STAT), R1_BAT.2
unnamed: C1_BAT1.1, D2.1 (CATHODE), IC4.1 (VIN), IC4.3 (CE), Q1.2 (S)
unnamed: CHG_LED.C, R1_BAT.1
unnamed: C4.1, D3.2 (A), D4.1 (K)
unnamed: MCP73831.5 (PROG), R2_BAT.2
unnamed: EPD_C2.2, J1.5
unnamed: EPD_C8.2, J1.20
unnamed: EPD_C12.2, J1.24
unnamed: EPD_C1.2, J1.4
unnamed: EPD_C10.2, J1.22
unnamed: C_DELAY.1, IC1.5 (CT)
unnamed: D7.1 (CATHODE), R_CAPACITOR.1
unnamed: EPD_C9.2, J1.21
unnamed: EPD_C7.2, J1.19
unnamed: EPD_C6.2, J1.18
PREVGH: D5.1 (K)
PREVGL: D4.2 (A), EPD_C11.2, J1.23
RESE: J1.3, Q3.2 (S), R3.2
RESE': R2.2, R3.1, SJ1.2
RESET: C5.1, IC1.1 (VOUT), RESET_BUTTON.3, RESET_BUTTON.4, R_RESET.2, U2.3 (EN)
RTC_RST: U2.16 (IO18), U3.4 (!RST)
RX: TP2.TP, U2.24 (RXD0/GPIO17)
SCK: D10.2, J1.13, J4.P5 (CLK), R6.2, TP8.TP, U1.6 (CLK), U2.6 (IO6)
SCL: J3.4, R2_PINH.2, SENSOR2.4 (SCK), U2.20 (IO22), U3.16 (SCL), U4.7 (SCL)
SDA: J3.3, R1_PINH.2, SENSOR2.3 (SDI), U2.19 (IO21), U3.15 (SDA), U4.8 (SDA)
SRC: C4.2, D5.2 (A), L1.1, Q3.3 (D)
SS_SD: D8.2, J4.P2 (CD/DAT3), R10.2, U2.4 (IO4)
TX: TP1.TP, U2.25 (TXD0/GPIO16)
USB_D+: D1.1 (I/O1_1), U2.14 (IO13)
USB_D-: D1.3 (I/O2_1), U2.13 (IO12)
VBAT: C2_BAT.1, MCP73831.3 (VBAT), Q1.3 (D), TP3.TP, U4.2 (CELL), U4.3 (VDD)
VBUS: C1_BAT.1, C4_USB.1, C5_USB.1, CHG_LED.A, D1.5 (VBUS), D2.2 (ANODE), MCP73831.4 (VIN), PFMF.050.1.2, Q1.1 (G), R1_PWRUSB.2, TP14.TP
VBUS1: C1.1, C2.1
VRTC: C8.2, C10_SUPERCAP.2, R_CAPACITOR.2, U3.14 (VBAT)
VUSB: J2.A4, J2.A9, J2.B4, J2.B9, PFMF.050.1.1

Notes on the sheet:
USB C connector & ESD protection
SD Card
LDO Voltage Regulator
Display Type Selector
E-Paper Drive Circuit
Li-Po Battery Charging Controller
ESP32 C6
E-Paper Dispaly Header
EPD Power
Environmental Sensor BME688
Voltage Supervisor + Reset & Boot/IO Button
Battery Charge Level
RTC Module DS3231SN
Test Pads
Qwiic/ Stema QT
SPI ESD Protection Lines
External NOR Flash 64MB
OpenBook Schematic
drawn by: Petrica Vladimir

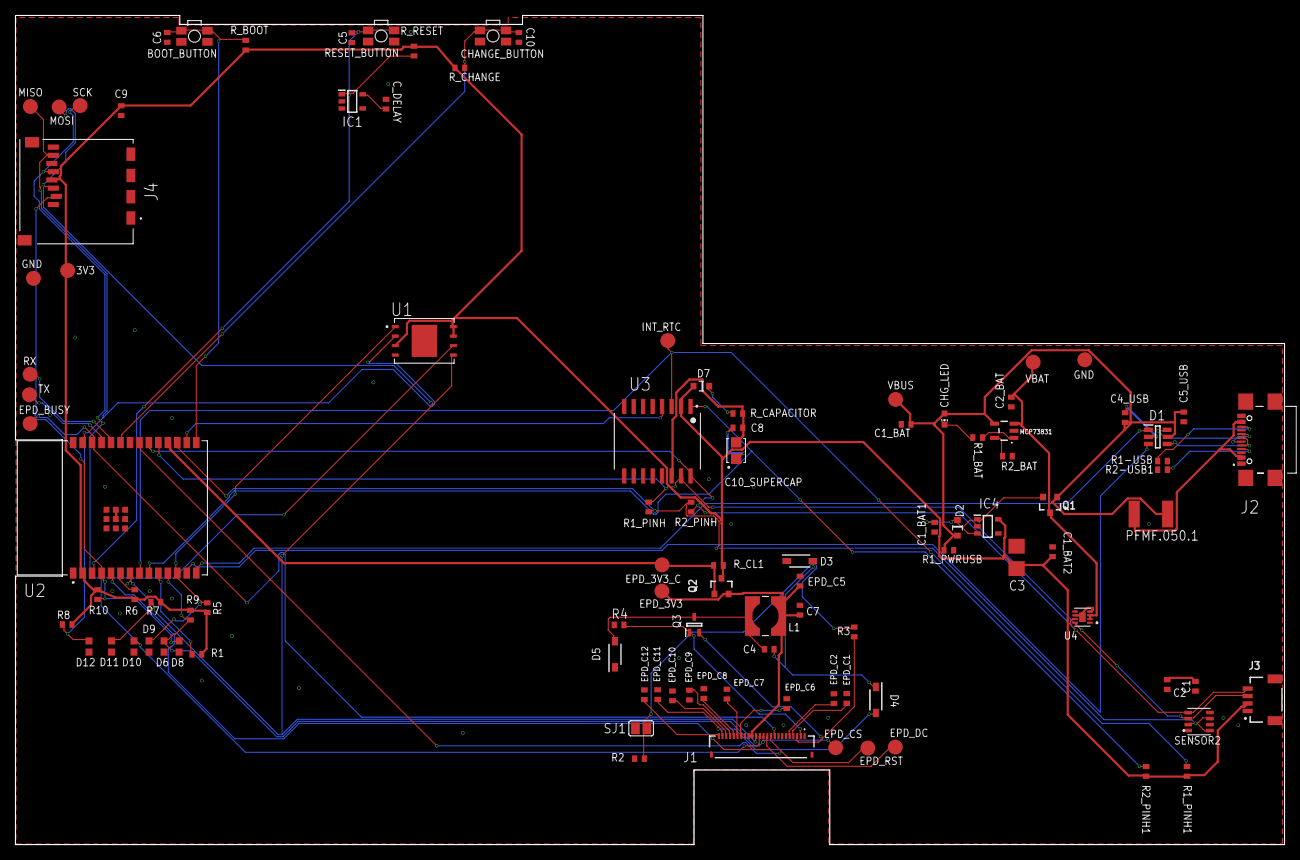
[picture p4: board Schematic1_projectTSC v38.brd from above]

Board: 2 copper layers, 170.2 x 111.2 mm, 103 parts (0 on the bottom side), 56 nets.

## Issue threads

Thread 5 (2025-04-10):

Grosime pcb prea mare (trebuie sa aiba 1mm grosime, nu 1.6 mm)

DianaChelaru, 2025-04-10:

DianaChelaru, 2025-04-11:
Placuta nu va intra in carcasa asa cum trebuie. Se poate rezolva: Rules->Preferences->Layer Stack.

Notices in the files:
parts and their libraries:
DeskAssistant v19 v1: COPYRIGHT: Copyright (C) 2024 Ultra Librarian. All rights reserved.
